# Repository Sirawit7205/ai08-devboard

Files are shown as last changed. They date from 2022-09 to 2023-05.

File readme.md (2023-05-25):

# AI08 Devboard

This is an open-source KiCAD design files for a development for [SAM&WING AI08](https://datasheet.lcsc.com/lcsc/2208221130_Sam-wing-AI08_C521987.pdf) 8-Channel Capacitive Touch Controller IC.

## Pictures

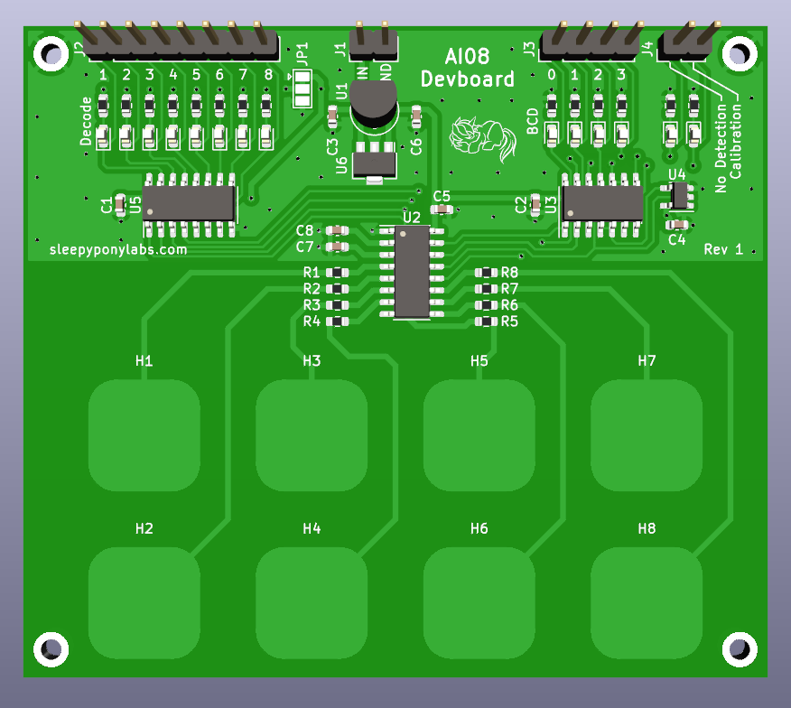
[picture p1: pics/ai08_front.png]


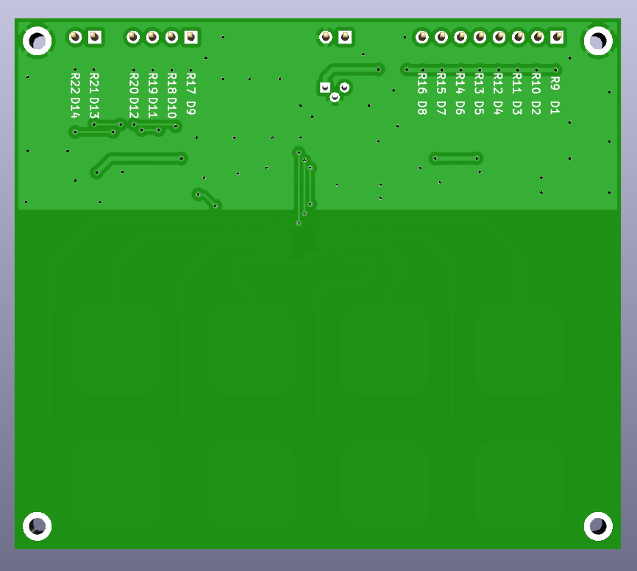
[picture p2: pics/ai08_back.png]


## Features

This devboard provides full flexibility for testing various configurations of the chip and surrounding circuits.

- AI08 Functions
	- Eight 12mm rounded-rectangle touch buttons. (No shield)
	- CSEL pad for sensitivity settings.
- Multiple Outputs
	- 4-bit BCD output (with indicator LEDs)
	- 8-bit decoded output (with indicator LEDs)
	- No Detection and Sleep Calibration indicator LEDs
	- 74HC138 is interchangable for 74HC238 for active-high decoded output.
- Built-In LDO
	- Built-in LDO for better noise reduction.
	- TO-92 and SOT-89 footprints.
	
## Revisions

We are currently at Revision 1. Changelog is below:

**Revision 1 (September 2022)**
 - Initial Design

## What is provided

The goal of this repository is to enable you to build this on your own as easy as possible (although I originally plan to sell this as a kit as well). **The schematics, PCB design, and an interactive BOM is provided.**

Hardware is licensed under `SPDX-License-Identifier: CERN-OHL-S-2.0`

Software is licensed under `SPDX-License-Identifier: GPL` (Actually there is no software for this board. Oops.)

Documentation is licensed under `SPDX-License-Identifier: CC-BY-SA-4.0`

**This project is an OSHWA Certified Open Source Hardware Project with UID [TH000011](https://certification.oshwa.org/th000011.html).**

## Ordering

You can export gerbers from this project and order the board yourself. You can also use the link below to directly order from Aisler.
https://aisler.net/p/NBMILDEY

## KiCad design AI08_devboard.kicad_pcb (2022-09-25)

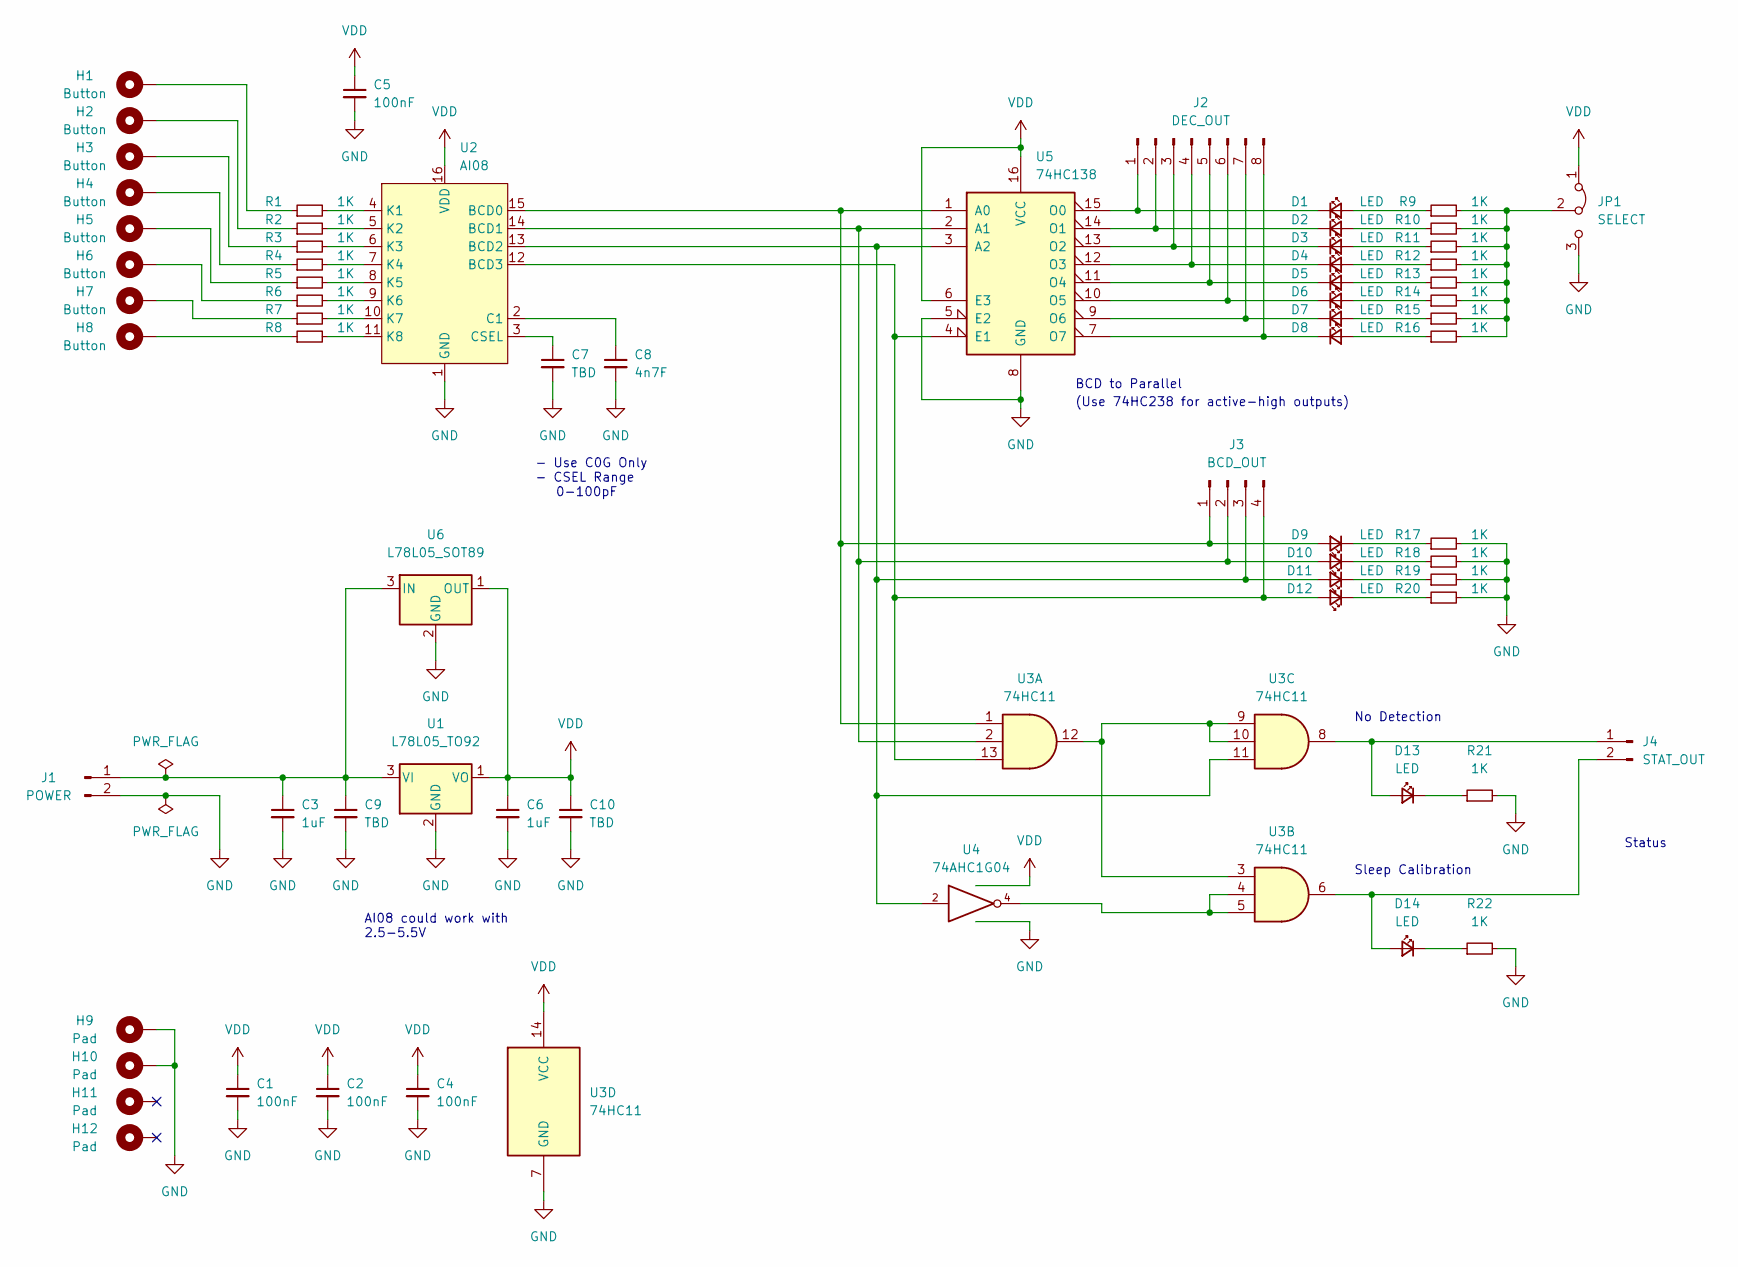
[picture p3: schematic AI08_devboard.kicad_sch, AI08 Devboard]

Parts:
C1, C2, C4, C5: 100nF; C_0603_1608Metric
C3, C6: 1uF; C_0805_2012Metric
C7: TBD; C_0603_1608Metric
C8: 4n7F; C_0603_1608Metric
C9, C10: TBD; C_0805_2012Metric
D1, D2, D3, D4, D5, D6, D7, D8, D9, D10, D11, D12, D13, D14: LED; LED_0603_1608Metric
H1, H2, H3, H4, H5, H6, H7, H8: Button; CAPTOUCH_12mm
H9, H10, H11, H12: Pad; MountingHole_2.2mm_M2_DIN965_Pad
J1: POWER; PinHeader_1x02_P2.54mm_Vertical
J2: DEC_OUT; PinHeader_1x08_P2.54mm_Vertical
J3: BCD_OUT; PinHeader_1x04_P2.54mm_Vertical
J4: STAT_OUT; PinHeader_1x02_P2.54mm_Vertical
JP1: SELECT; SolderJumper-3_P1.3mm_Bridged12_Pad1.0x1.5mm
R1, R2, R3, R4, R5, R6, R7, R8, R9, R10, R11, R12, R13, R14, R15, R16, R17, R18, R19, R20, R21, R22: 1K; R_0603_1608Metric
U1: L78L05_TO92; TO-92
U2: AI08; SOIC-16_3.9x9.9mm_P1.27mm
U3: 74HC11; SOIC-14_3.9x8.7mm_P1.27mm
U4: 74AHC1G04; SOT-23-5
U5: 74HC138; SOIC-16_3.9x9.9mm_P1.27mm
U6: L78L05_SOT89; SOT-89-3

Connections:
GND: C1.2, C2.2, C3.2, C4.2, C5.2, C6.2, C7.2, C8.2, C9.2, C10.2, H9.1, H10.1, J1.2, JP1.3 (B), R17.2, R18.2, R19.2, R20.2, R21.2, R22.2, U1.2 (GND), U2.1 (GND), U3.7 (GND), U4.3 (GND), U5.5 (E2), U5.8 (GND), U6.2 (GND)
unnamed: C7.1, U2.3 (CSEL)
unnamed: C8.1, U2.2 (C1)
unnamed: D1.1 (K), J2.1, U5.15 (O0)
unnamed: D1.2 (A), R9.1
unnamed: D2.1 (K), J2.2, U5.14 (O1)
unnamed: D2.2 (A), R10.1
unnamed: D3.1 (K), J2.3, U5.13 (O2)
unnamed: D3.2 (A), R11.1
unnamed: D4.1 (K), J2.4, U5.12 (O3)
unnamed: D4.2 (A), R12.1
unnamed: D5.1 (K), J2.5, U5.11 (O4)
unnamed: D5.2 (A), R13.1
unnamed: D6.1 (K), J2.6, U5.10 (O5)
unnamed: D6.2 (A), R14.1
unnamed: D7.1 (K), J2.7, U5.9 (O6)
unnamed: D7.2 (A), R15.1
unnamed: D8.1 (K), J2.8, U5.7 (O7)
unnamed: D8.2 (A), R16.1
unnamed: D9.1 (K), R17.1
unnamed: D9.2 (A), J3.1, U2.15 (BCD0), U3.1, U5.1 (A0)
unnamed: D10.1 (K), R18.1
unnamed: D10.2 (A), J3.2, U2.14 (BCD1), U3.2, U5.2 (A1)
unnamed: D11.1 (K), R19.1
unnamed: D11.2 (A), J3.3, U2.13 (BCD2), U3.11, U4.2, U5.3 (A2)
unnamed: D12.1 (K), R20.1
unnamed: D12.2 (A), J3.4, U2.12 (BCD3), U3.13, U5.4 (E1)
unnamed: D13.1 (K), R21.1
unnamed: D13.2 (A), J4.1, U3.8
unnamed: D14.1 (K), R22.1
unnamed: D14.2 (A), J4.2, U3.6
unnamed: H1.1, R1.1
unnamed: H2.1, R2.1
unnamed: H3.1, R3.1
unnamed: H4.1, R4.1
unnamed: H5.1, R5.1
unnamed: H6.1, R6.1
unnamed: H7.1, R7.1
unnamed: H8.1, R8.1
unnamed: C3.1, C9.1, J1.1, U1.3 (VI), U6.3 (IN)
unnamed: R1.2, U2.4 (K1)
unnamed: R2.2, U2.5 (K2)
unnamed: R3.2, U2.6 (K3)
unnamed: R4.2, U2.7 (K4)
unnamed: R5.2, U2.8 (K5)
unnamed: R6.2, U2.9 (K6)
unnamed: R7.2, U2.10 (K7)
unnamed: R8.2, U2.11 (K8)
unnamed: JP1.2 (C), R9.2, R10.2, R11.2, R12.2, R13.2, R14.2, R15.2, R16.2
unnamed: U3.4, U3.5, U4.4
unnamed: U3.3, U3.9, U3.10, U3.12
VDD: C1.1, C2.1, C4.1, C5.1, C6.1, C10.1, JP1.1 (A), U1.1 (VO), U2.16 (VDD), U3.14 (VCC), U4.5 (VCC), U5.6 (E3), U5.16 (VCC), U6.1 (OUT)

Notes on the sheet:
- Use C0G Only - CSEL Range 0-100pF
No Detection
Status
AI08 could work with 2.5-5.5V
Sleep Calibration
BCD to Parallel
(Use 74HC238 for active-high outputs)

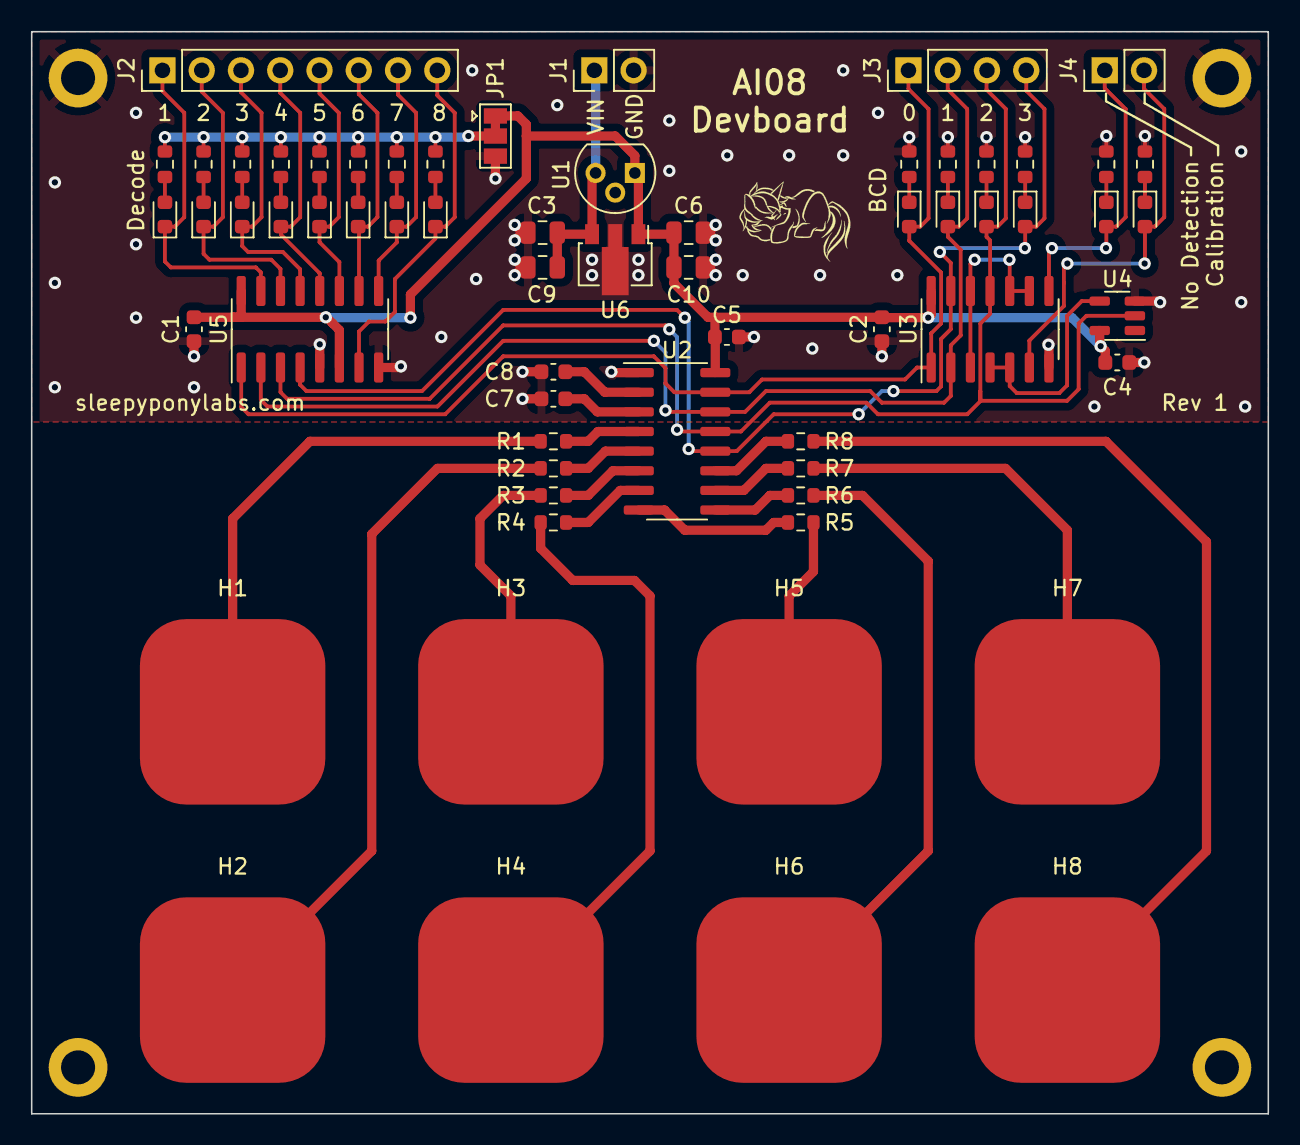
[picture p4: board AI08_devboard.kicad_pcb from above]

Board: 2 copper layers, 80.0 x 70.0 mm, 69 parts (0 on the bottom side), 52 nets.
